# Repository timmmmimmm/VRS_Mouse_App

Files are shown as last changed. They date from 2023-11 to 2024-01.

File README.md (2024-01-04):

# DIY 3D Mouse for CAD programs

- code on STM32F303K8
- Drivers
  - TLV493D (3-axis magnetometer)
  - W25Q32 (flash)
- 3D Models of mouse
- Windows utilities
  - python server for communication
  - python script for keyboard commands
  - python script for USART communication
  - WPF GUI in C#

# About

This project aims to help CAD designers create their own 3D DIY Mouse for a cheaper price than usual.

With a 3D Mouse, a designer is able to model significantly faster than with a classic 2D mouse.
The brain of our project is a microcontroller STM32F303K8, which communicates with a 3D magnetic
sensor TLV493D and transforms its data, so that they can be used in a CAD programme. This, in turn reduces
the amount of movements necessary for certain operations (e.g. rotation of an object).

The project allows users to configure their own mouse sensitivity in the form of DPI and to choose their own Action Buttons using the Windows App. Data for mouse sensitivity and key bindings are stored on an external flash memory chip W25Q32. 

# Drivers

We created drivers in the StmCubeIDE for all external HW.

## TLV493D

The 3D magnetic sensor TLV493D-A1B6 detects the magnetic flux density in three directions; x, y and z. The
magnetic flux density in the z-direction (Bz) is detected by a lateral-Hall plate parallel to the surface of the
chip. The magnetic flux density in the x- and y-direction (Bx and By) are detected by vertical-Hall plates
perpendicular to the surface of the chip.

<p align="center">
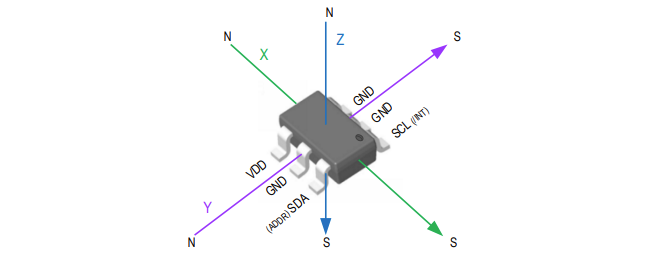
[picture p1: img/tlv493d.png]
    
</p>

The MCU communicates with the sensor over I2C.

## W25Q32

External serial flash memory W25Q32 (32M-bit) serves as a storage place for user configuration of DPI and Action Buttons. 
It is organized into 64 blocks, each consisting of 16 sectors, each consisting of 16 programmable pages of 256-bytes each. Together that is 4MB of storage space. 

<p align="center">
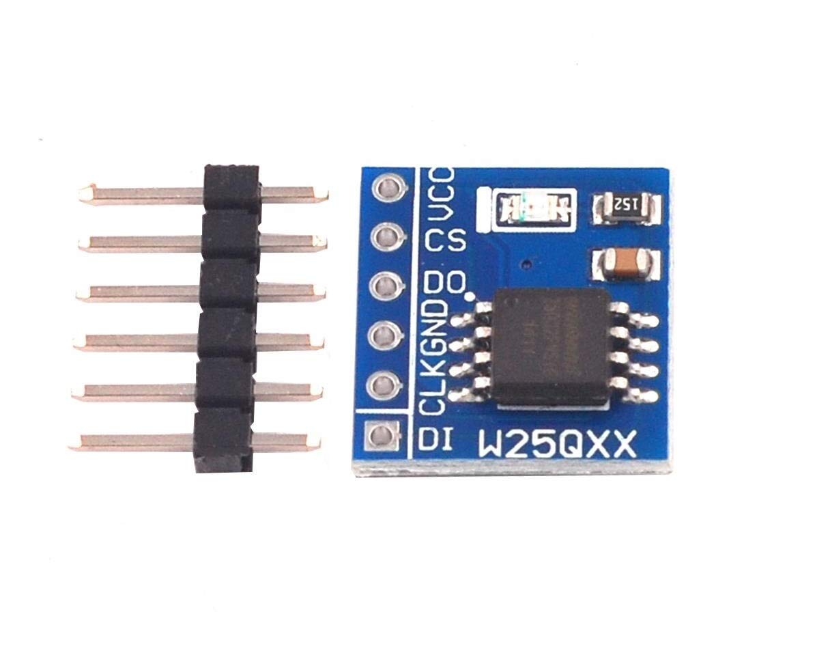
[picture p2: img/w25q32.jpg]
Flash W25Q32
    
</p>

The W25Q32 supports SPI which is used for communication with the STM32F303K8.

## Sending commands to PC
### Python script
For the proper function of the 3D mouse, it is necessery to start a python script, which handles communication with STM32 and the Windows application.
  
#### Main thread
The main thread of the python script listens to JSON messages sent by STM32 through USART, which consist of 3 values representing rotation of axes. On top of that, if a button was pressed, which had previously been configured with the App, the STM32 will also send a numerical value representing the specific bind of the Action Button.
This thread is also able to read or write data to the STM32, which represents the current configuration of mouse sensitivity and Action Buttons.
#### Server thread
The server thread of our python script handles HTTP communication with the Windows Application. It creates a localhost server on port 12345 and offers two types of requests for clients. The first request is a GET request with the path /ma/api/all which returns a JSON message consisting of DPI, Action Button 0 and Action Button 1. The second request is of type POST and requires a JSON body consisting of the same configuration parameters as mentioned in the previous request.

# Models

Folder models contains .stl model files which are the 3D representation of 3D mouse.

# App

The PC app is a WPF GUI, which communicates with the microcontroller via UART trough a IO port.

It provides seamless communication without the user knowing anything about the device.

Since the app uses WPF it is only available on Windows 10 or higher.

<p align="center">
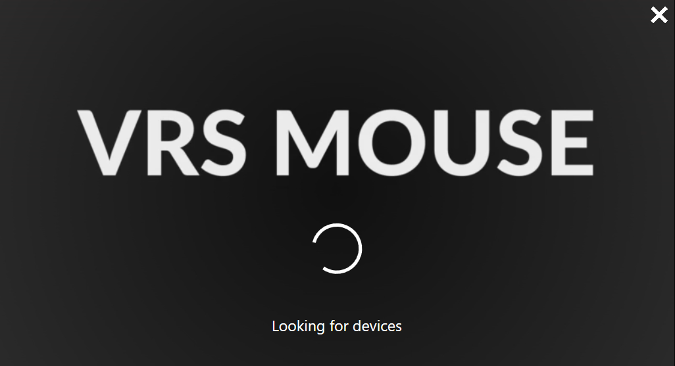
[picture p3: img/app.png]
    
</p>

## Features

  ### Provides basic mouse information

 <p align="center">
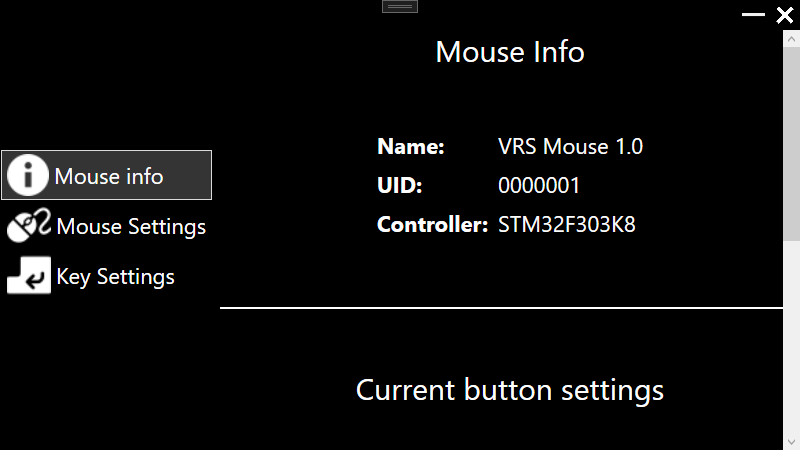
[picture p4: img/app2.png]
    
</p>

  ### Button mapping

 <p align="center">
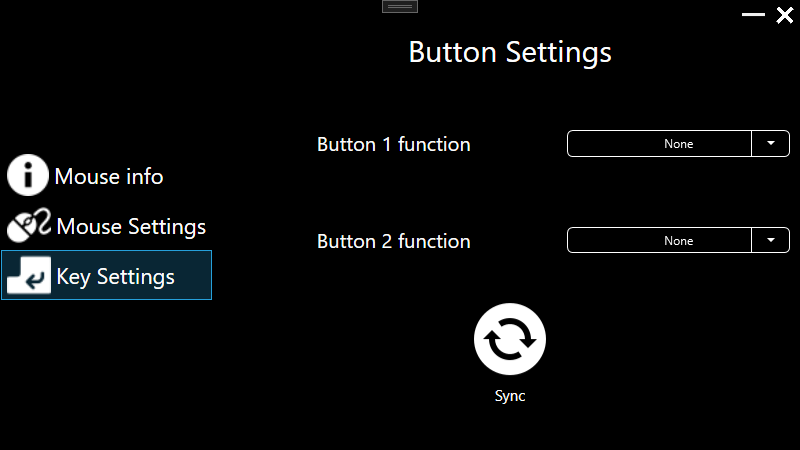
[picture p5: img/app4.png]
    
</p>

  ### Mouse axis sensitivity settings

 <p align="center">
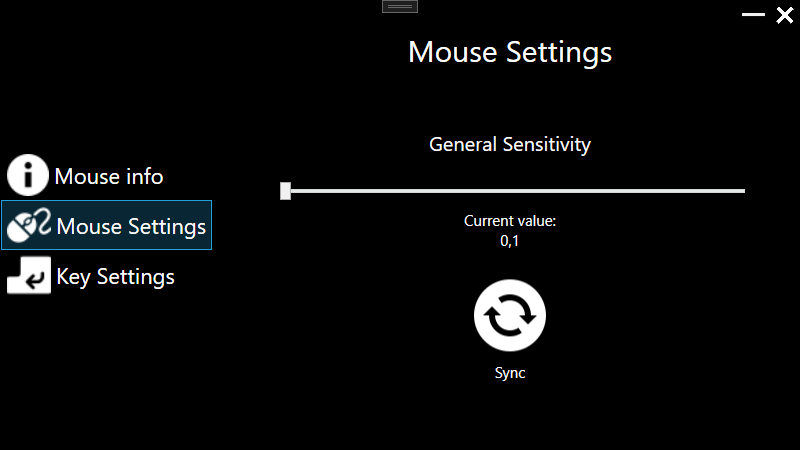
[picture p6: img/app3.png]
    
</p>

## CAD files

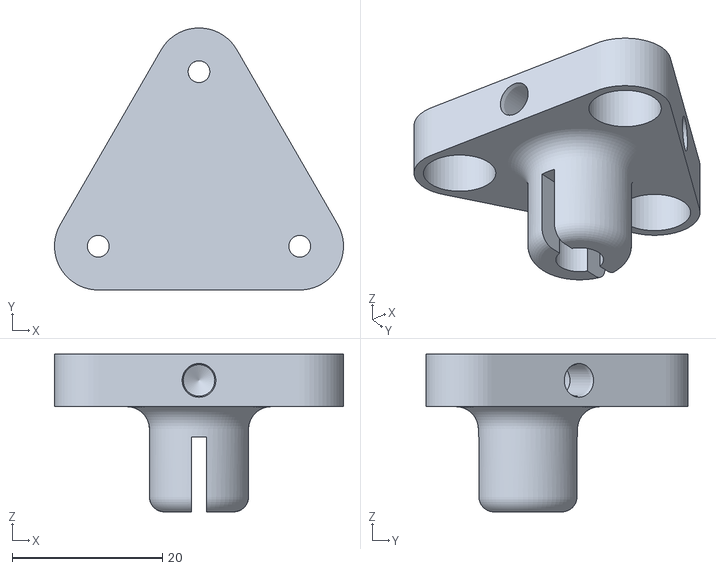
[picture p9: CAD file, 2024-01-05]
models/Stem_top.stl
38.4 x 34.9 x 21.0

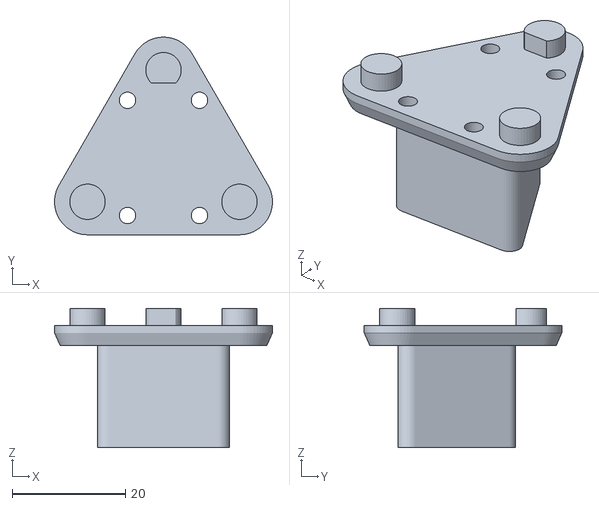
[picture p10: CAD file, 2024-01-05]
models/Stem_bottom.stl
38.4 x 34.9 x 24.6

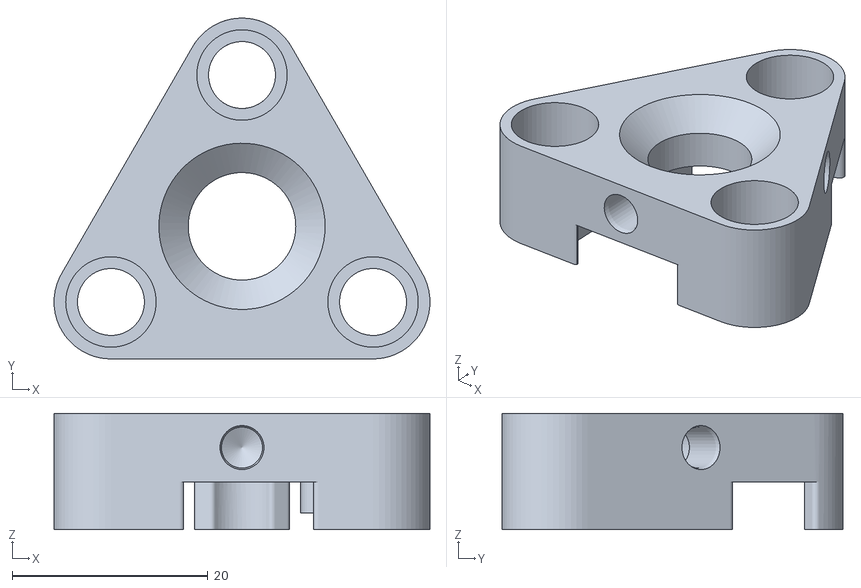
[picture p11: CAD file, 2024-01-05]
models/Stem_middle.stl
38.5 x 34.9 x 11.9

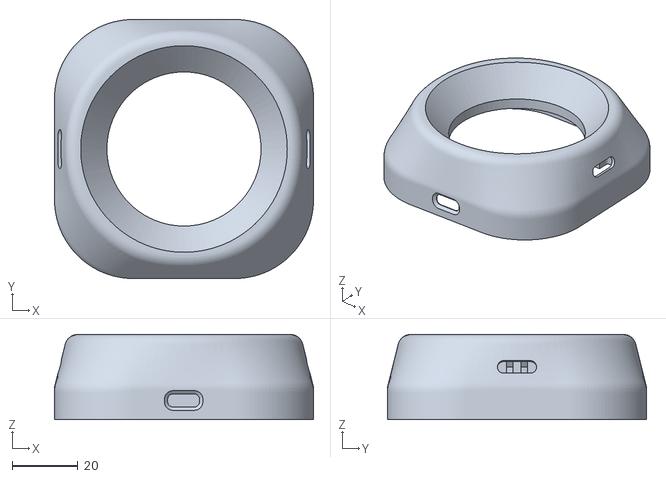
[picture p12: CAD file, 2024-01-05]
models/Base_top.stl
79.0 x 79.0 x 26.0

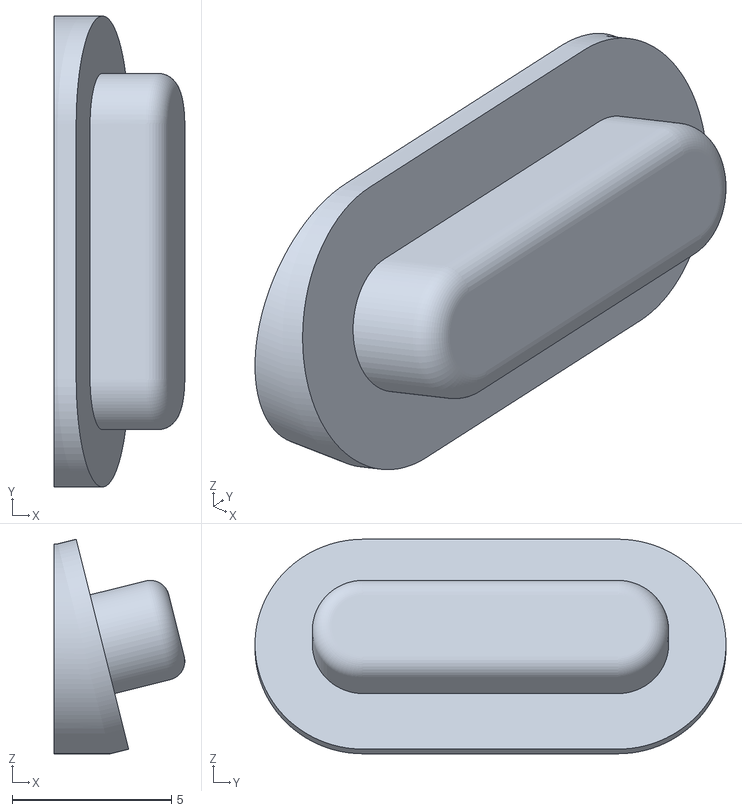
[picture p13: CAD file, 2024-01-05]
models/Buttons.stl
4.10 x 14.8 x 6.74

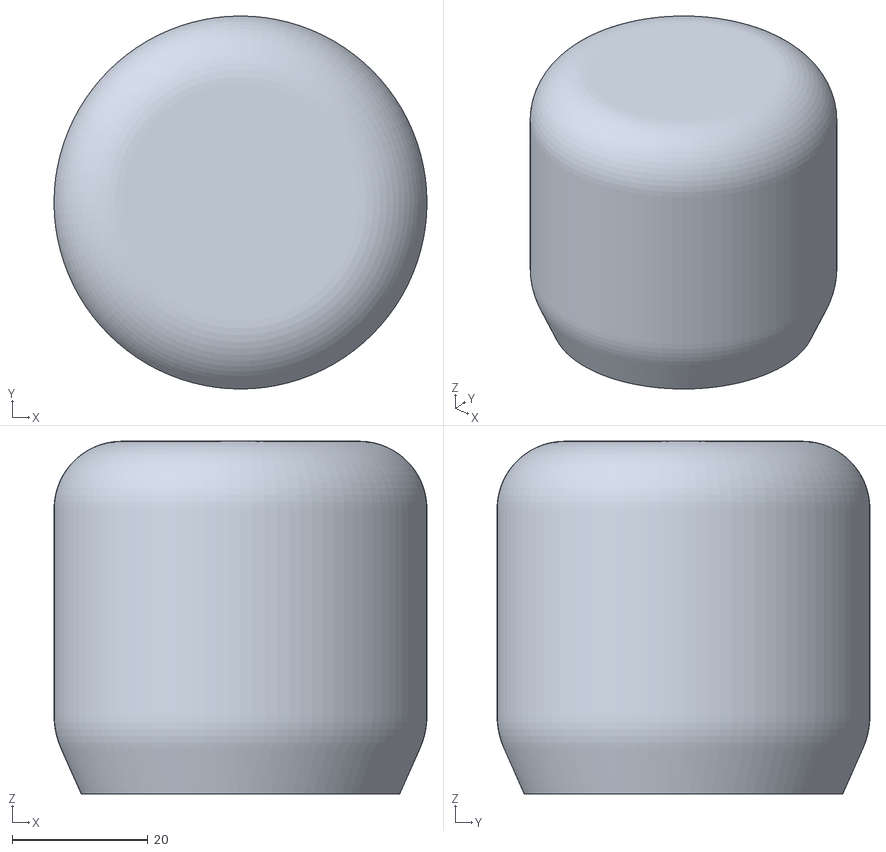
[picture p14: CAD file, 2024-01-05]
models/Knob.stl
55.0 x 55.0 x 52.0

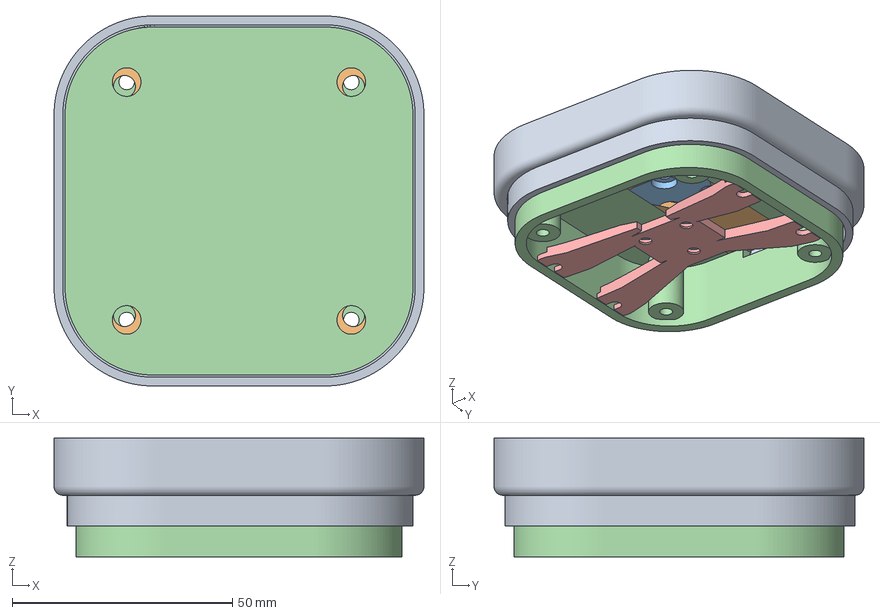
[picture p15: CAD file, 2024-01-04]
models/all_in_one.FCStd
84.0 x 84.0 x 27.0 mm
ring_joystivk
middle_part
joystick_holder
bottom_plate_2_0
joystick_holder001

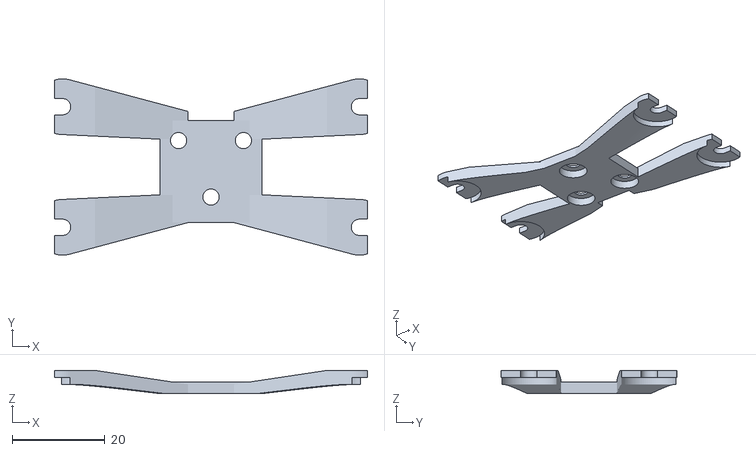
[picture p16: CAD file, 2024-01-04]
models/knob_holder.stl
67.5 x 38.0 x 5.00

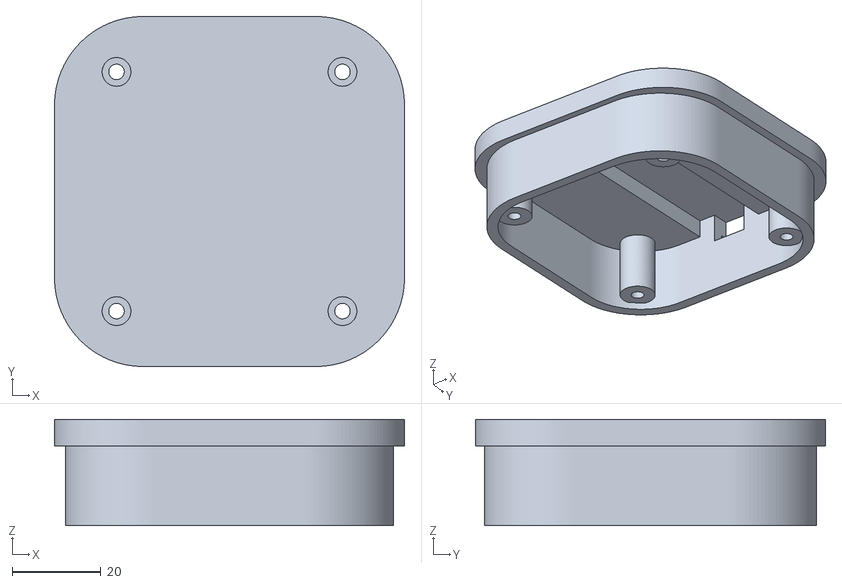
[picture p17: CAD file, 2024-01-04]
models/bottom_plate.stl
79.0 x 79.0 x 24.0

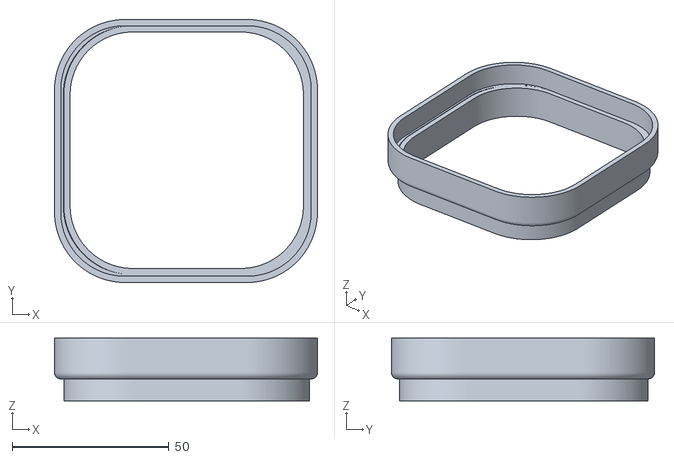
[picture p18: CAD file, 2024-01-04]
models/ring_mouse.stl
84.0 x 84.0 x 20.0

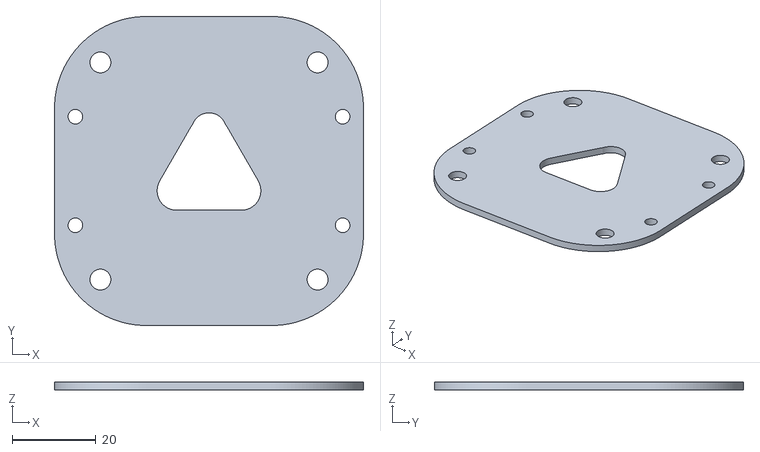
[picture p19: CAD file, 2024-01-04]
models/middle_plate.stl
74.0 x 74.0 x 2.00

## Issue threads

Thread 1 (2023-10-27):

Handshake with APP

KocurMaros, 2023-10-27:
1. Create  verifier with timer
- [x] device - sending string to USART (Serial Number/MAC address)
- [ ] APP - waiting for string on USART (when it comes stop sending device verifier)
- [ ] after established connection read param from EEPROM/FLASH and send them to APP
- [ ]  wait for param from APP
- [ ] write param to EEPROM/flash

timmmmimmm, 2024-01-06:
Bruuh, that was did like half a year ago

Closed 2024-01-06.

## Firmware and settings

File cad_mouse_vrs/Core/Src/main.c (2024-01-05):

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
/* Includes ------------------------------------------------------------------*/
#include "main.h"
#include "dma.h"
#include "i2c.h"
#include "spi.h"
#include "tim.h"
#include "usart.h"
#include "gpio.h"
#include "stm32f3xx_it.h"
#include "tlv493c/tlv493.h"
#include "W25Q32.h"
#include "movingAverageFIlter.h"
#include "mouseAxisPostProcessing.h"

/* USER CODE BEGIN PV */
bool change_in_conf = false;
/* USER CODE END PV */

void SystemClock_Config(void);
/* USER CODE BEGIN 0 */
void create_message(uint8_t *message, uint8_t *len, int16_t rot_x, int16_t rot_y, int16_t rot_z);
/* USER CODE END 0 */

/**
  * @brief  The application entry point.
  * @retval int
  */
int main(void)
{
  /* MCU Configuration--------------------------------------------------------*/

  /* Reset of all peripherals, Initializes the Flash interface and the Systick. */
  HAL_Init();

  /* USER CODE BEGIN Init */
  W25Q32_REGISTER_CALLBACKS(SPI_Receive,SPI_Send,GPIO_SPI_CS_LOW,GPIO_SPI_CS_HIGH,SPI_Delay);
  USART2_RegisterCallback(proccesDmaData);
  /* USER CODE END Init */

  /* Configure the system clock */
  SystemClock_Config();

  /* Initialize all configured peripherals */
  MX_GPIO_Init();
  MX_DMA_Init();
  MX_USART2_UART_Init();
  MX_I2C1_Init();
  MX_TIM15_Init();
  MX_SPI1_Init();
  /* USER CODE BEGIN 2 */
  W25Q32_RESET();
  W25Q32_GET_ID();

//  W25Q32_WRITE_ACTION_BUTTON_0(5);
//  W25Q32_WRITE_ACTION_BUTTON_1(2);
  // W25Q32_WRITE_DPI(1);
  (void)tlv493_init(i2c_master_read, i2c_master_write, HAL_Delay);
  initFilter(tlv493_getX, tlv493_getY, tlv493_getZ, tlv493_update_data, HAL_Delay);
  uint16_t dpi = 1;
	dpi = W25Q32_READ_DPI();
	if(dpi > 20 || dpi < 0)
		dpi = 1;
	dpi *= 50;
	dpi = (uint16_t)(1000/(1050-dpi)); //spytat sa tima ci bude problem nastavit sesitivitu 1-20
  /* USER CODE END 2 */

  /* Infinite loop */
  /* USER CODE BEGIN WHILE */

  uint8_t message[256];
  uint8_t length;
  MouseAxisInfo *mouseAxisInfo = 0;

  while (1)
  {
    /* USER CODE END WHILE */
	  //pride vzdy predosla hodnota a ty ju prepocitas napr predosla je 60deg dalsie 61 tak neotoci ju o 61 dlasich ale len o 1 ?
	  //akoze neviem ci to dava zmysel alebo pokiaal drzi do strany tak zeby to posuvalo ?
	  //idk mozme dat discusion
	  //vo funkci si zavolaj najprv tlv493_update_data(); a potom getX()...
//	  calc_rot(&rotX,&rotY,&rotZ,&zoom);
	  if(change_in_conf){
		    dpi = W25Q32_READ_DPI();
			if(dpi > 20 || dpi < 0)
				dpi = 1;
			dpi *= 50;
			dpi = (uint16_t)(1000/(1050-dpi));
			change_in_conf = false;
	  }
	  mouseAxisInfo = MA_filterData();

	  mouseAxisInfo = PP_ProcessData(mouseAxisInfo,dpi);

	  create_message(message, &length, mouseAxisInfo->x, mouseAxisInfo->y, mouseAxisInfo->z);
	  USART2_PutBuffer(message, length);
	  HAL_Delay(1);

    /* USER CODE BEGIN 3 */
  }
  /* USER CODE END 3 */
}

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
/* USER CODE BEGIN 4 */
void proccesDmaData(const uint8_t* data, uint8_t len)
{
	//this function parses 3 numbers representing DPI, ACTION BUTTON 0 and ACTION BUTTON 1 and writes them to the flash
	uint16_t numbers[3];
	static uint8_t k=0;
	static uint8_t counter = 0;
	for (uint8_t i= 0;i<len;i++){
		if ((data[i]<='9')&&(data[i]>='0')){
			if (counter==0){
				numbers[k]=data[i]-'0'; //first digit
			}
			else{
				numbers[k]=numbers[k]*10+(data[i]-'0');
			}
			counter++;
		}
		else if (data[i]==','){
			k++;
			counter=0;
		}
		else if (data[i]=='$'){
			uint16_t a=W25Q32_READ_DPI();
			uint8_t b=W25Q32_READ_ACTION_BUTTON_0();
			uint8_t c=W25Q32_READ_ACTION_BUTTON_1();
			char tx_buffer[128];
			uint16_t len = sprintf(tx_buffer, "{\"dpi\":%d,\"button0\":%d,\"button1\":%d}\r\n",a,b,c);
			USART2_PutBuffer((uint8_t*)tx_buffer, len);
			k=0;
			break;
		}
	}
	if (k>=2){  //if there were 3 numbers sent
		change_in_conf = true;
		W25Q32_WRITE_DPI(numbers[0]);
		W25Q32_WRITE_ACTION_BUTTON_0(numbers[1]);
		W25Q32_WRITE_ACTION_BUTTON_1(numbers[2]);
		k=0;
	}

}
void create_message(uint8_t *message, uint8_t *len, int16_t rot_x, int16_t rot_y, int16_t rot_z){
	uint8_t but0 = 0, but1 = 0;
  /**
   * @brief button actions
   * 0 - nothing
   * 1 - HOME (F6)
   * 2 - Cancel (ESC) 
   * 3 - Previous (F5)  
   * 4 - Zoom ALL (HOME)
   *
  */

	if(get_button(0)){
		but0 = W25Q32_READ_ACTION_BUTTON_0();
		reset_button(0);
	}
	if(get_button(1)){
		but1 = W25Q32_READ_ACTION_BUTTON_1();
		reset_button(1);
	}

	///////////////////////////////////////////  ARDUINO DEBUG  ///////////////////////////////////////////
//	*len = (uint8_t)sprintf((char*)message,
//					"RotX:%d,RotY:%d,Zoom:%d,Btn1:%d,Btn2:%d\r\n",
//					rot_x,rot_y,rot_z,0,0);

	///////////////////////////////////////////  Production  ///////////////////////////////////////////
	*len = (uint8_t)sprintf((char*)message,
						"{\"RotX\":%d,\"RotY\":%d,\"Zoom\":%d,\"Button0\":%d,\"Button1\":%d}\r\n",
						rot_x,rot_y,rot_z,but0,but1);

}
/* USER CODE END 4 */
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


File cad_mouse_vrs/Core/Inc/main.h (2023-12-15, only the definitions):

#define MCO_Pin LL_GPIO_PIN_0
#define MCO_GPIO_Port GPIOF
#define VCP_TX_Pin LL_GPIO_PIN_2
#define VCP_TX_GPIO_Port GPIOA
#define SPI1_CS_Pin LL_GPIO_PIN_8
#define SPI1_CS_GPIO_Port GPIOA
#define Button0_Pin LL_GPIO_PIN_10
#define Button0_GPIO_Port GPIOA
#define Button0_EXTI_IRQn EXTI15_10_IRQn
#define Button1_Pin LL_GPIO_PIN_11
#define Button1_GPIO_Port GPIOA
#define Button1_EXTI_IRQn EXTI15_10_IRQn
#define SWDIO_Pin LL_GPIO_PIN_13
#define SWDIO_GPIO_Port GPIOA
#define SWCLK_Pin LL_GPIO_PIN_14
#define SWCLK_GPIO_Port GPIOA
#define VCP_RX_Pin LL_GPIO_PIN_15
#define VCP_RX_GPIO_Port GPIOA

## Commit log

2023-10-13 Added bottom prompt, started on retry button animation, and port connectivity
2023-10-26 USART Driver
2023-10-27 timer 15
2023-10-27 remove i2c EXTI from stm_it and add conf of RX/TX to usart
2023-10-27 i2c handler
2023-10-27 driver for tlv493
2023-10-29 i2c driver
2023-10-29 timer
    kazde 2s posle string
2023-10-29 Fixed a bad practise, where I ignored com ports, Fixed a bug where a thread was left running after the app shut down, Increased the lookup timer to 10s
2023-10-30 timer fix
    odstraneny FFFF, printovanie cez putBuffer
    [main.c]
2023-10-30 Some button styling, fixed video playback on 2nd monitor, added button functionality for the main window, added a static class for easyer string access
2023-11-07 driver to c
2023-11-15 idem opravit i2c
2023-11-15 TIM nepregenerovava uz, added SPI for code gen,
2023-11-15 added some things to spi
2023-11-15 added functions for read and write spi, interrupt
2023-11-15 spi wrong ..
2023-11-16 rewrote spi, works? dunno will have to test, but looking sexy af
2023-11-20 testy i2c
2023-11-26 i2c error fixed
2023-11-26 checknut ci spi sa nebije s i2c
2023-11-26 spi testing
2023-12-04 changed spi read/write as callback functions
2023-12-04 replaced delay with callback delay, added functions into .h file
    [main.c]
2023-12-04 added functionality for DPI, action button 0 and 1
2023-12-04 added spi configuration back
2023-12-07 fixed spi, i2c conflict
    [cad_mouse_vrs.ioc]
2023-12-07 added button interrupts
2023-12-15 Started work on a moving average filter
2023-12-15 Filter implemented, buut nothing changed, moving the filter to a timer
2023-12-22 THE FUCKING SENSOR IS FINALY WORKING
2023-12-22 0 Warnings, adequate filtering
2023-12-22 Worknig on the pytho script, as of now it is too slow
    [main.c]
2023-12-27 added one more ',' into python script, refactored usart callback function to send json type data of dpi, button0 and button1
2024-01-03 double interrupt fixed and fade but now is commented
    [tlv493.c]
2024-01-04 Remove old version of board
2024-01-04 some models + readme.md
    [bottom_plate.stl, bottom_plate_2_0.stl, joystick_holder.stl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]
2024-01-04 multi thread read and perform
2024-01-04 Added current build dir + app receives data, somewhat
2024-01-05 all models
    [Base_top.stl, Buttons.stl, Knob.stl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]
2024-01-05 button actions
2024-01-05 Bug fixes for non - connected device on driver startup and Autocad manipulation when Inventor is closed (startup and while running the script)
2024-01-06 App cosmetics reworked, fixed some buggs which occured when the mouse got unplugged, fixed buggy behaviour after button presses, Adjusted Zooming constants for better feel and controll
2024-01-07 Create 3D CAD Mouse.pptx
    presentation

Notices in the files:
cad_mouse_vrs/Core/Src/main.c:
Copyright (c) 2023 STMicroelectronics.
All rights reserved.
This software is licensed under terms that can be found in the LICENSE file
